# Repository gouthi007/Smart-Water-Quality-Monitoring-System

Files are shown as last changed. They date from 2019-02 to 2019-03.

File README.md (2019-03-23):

# Smart-Water-Quality-Monitoring-System

The aim of this project is to develop a Smart Water Quality Monitoring S System for testing the quality of water, using pH, temperature and u turbidity as the parameters, and User-Friendly Real-time Tracking Interface. The collective data is utilized to evaluate the quality of water, and to determine if the water quality is sufficient enough for domestic usage. The main goal is to develop a compact, cost-effective device to measure the appropriate parameters through the respective sensors, that uploads the compressed data to the cloud in a periodic basis, and to develop a Webpage that allows to monitor the quality levels on a real-time basis.

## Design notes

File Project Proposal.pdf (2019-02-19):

## EE701: Internet of Things: From Technology to Application

PROJECT PROPOSAL

Project Title | : Smart Water Quality Monitoring System
Team Members | : Hiren Aravind Murugudu Govindarajan
| Goutham Balasubramaniam
| Sai Ramya Gundala
| Zhe Li

Project Description : The aim of this project is to develop a Smart Water Quality Monitoring
S | System for testing the quality of water, using pH, temperature and
u | turbidity as the parameters, and a User-Friendly Real-time Tracking I
n | Interface. The collective data is utilized to evaluate the quality of water,
a | and to determine if the water quality is sufficient enough for domestic
s | usage. The main goal is to develop a compact, cost-effective, biosafe
e | device to measure the appropriate parameters through the respective
e | sensors, that uploads the compressed data to the cloud in a periodic b
a | basis, and to develop a Webpage that allows to monitor the quality-l e
v | levels on a real-time basis.

PROJECT OVERVIEW:

HARDWARE:

The following list of components will be used in the building of the monitoring device and is accompanied by the specifications and the cost for corresponding components. It is followed by links to the vendors for all the components.

Components | Model Number | Cost
Waterproof Temperature Sensor | DS18B20 | $10.99 (Set of 5)
Turbidity Sensor | SEN0189 | $19.69
pH Sensor | YY6237 | $33.59
Water Level Sensor | MC050-5 | $6.89 (Set of 5)
TI Board | CC2650 | Present with the team
SIGFOX Module | RC1692HP
Total | | $77.15

SENSORS’ DESCRIPTION:

1. Temperature Sensor: To measure the temperature of water (a requirement in cold places)
2. Turbidity Sensor: To indicate the level sediments/cloudiness by suspended particles in water. More turbidity can obstruct light to aquatic plants and also indicates the presence of high bacteria count.
3. pH Sensor: To indicate the presence of chemicals.
4. Water Level Sensor: To prevent the module from getting completely immersed by sending an alarm/notification.

SENSORS’ LINK:

### 1. Temperature Sensor-

https://www.amazon.com/HiLetgo-DS18B20-Temperature-Stainless-Waterproof/dp/B00M1PM55K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 (https://www.amazon.com/HiLetgo-DS18B20-Temperature-Stainless-Waterproof/dp/B00M1PM55K?hvadid=241906416474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)

### 2. Turbidity Sensor-

https://www.amazon.com/gp/product/B078JHBDJK/ref=ox_sc_act_title_2?smid=A2M99LKXDQEZXD&psc=1 (https://www.amazon.com/gp/product/B078JHBDJK/ref=ox_sc_act_title_2?smid=A2M99LKXDQEZXD&psc=1)

### 3. pH Sensor-

https://www.amazon.com/GAOHOU-PH0-14-Detect-Electrode-Arduino/dp/B0799BXMVJ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 (https://www.amazon.com/GAOHOU-PH0-14-Detect-Electrode-Arduino/dp/B0799BXMVJ?s=industrial)

### 4. Water Level Sensor-

https://www.amazon.com/gp/product/B01FDGU95Q/ref=ox_sc_act_title_3?smid=ADV3ON8ONZPPL&psc=1 (https://www.amazon.com/gp/product/B01FDGU95Q/ref=ox_sc_act_title_3?smid=ADV3ON8ONZPPL&psc=1)

SOFTWARE:

The project also involves developing a Static Webpage that provides a User-friendly Web-Interface(AWS Service) to allow real-time tracking of Water-Quality levels, which allows the user to see the latest data available or a time-series data for a particular location either by searching for that location or clicking on the corresponding location on the map. Once the hardware device is connected and sending data to the Sigfox Network, a native AWS IoT connector has to be configured to push the data to AWS cloud, which requires a CloudFormation script that will generate IAM roles and permissions. The data is stored in an Amazon DyanamoDB table by creating a manual rule. Also, Javascript and HTML is to be used to use the Google maps embed API interaction.

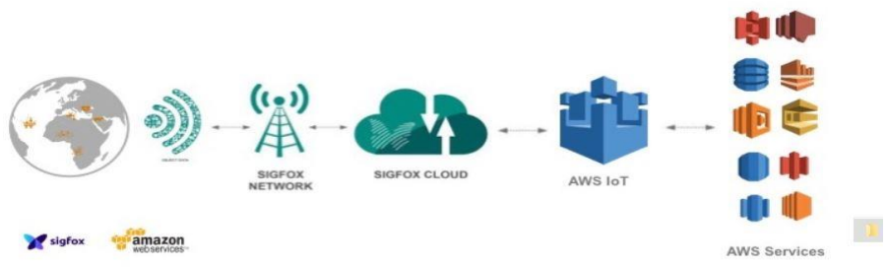
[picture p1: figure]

WORK PLAN/DIVISION of WORK:

Process Step | Resources Needed | Expected Effort | Due date
Hardware Requirements | Required: Hiren, Li Optional: Goutham, Ramya | 1-day of pre-work (3) 2-hour meetings | 11/11/2018
Hardware Development and Testing | Required: Hiren, Li, Goutham Optional: Ramya | 2-days of pre-work (8-10) 2-hour meetings | 11/18/2018
Hardware Enclosure Development | Required: Hiren, Li, Goutham Optional: Ramya | 1-day of pre-work (6-7) 2-hour meetings | 12/2/2018
Webpage Development | Required: Goutham, Ramya | (10) 2-hour meetings | 11/25/2018
System Integration and Testing | Required: Hiren, Goutham, Li, Ramya | (6) 2-hour meetings | 11/28/2018
Project Review And Remodeling | Required: Hiren, Goutham, Li, Ramya | (6) 2-hour meetings | 12/5/2018
Documentation/ Cost-Analysis | Required: Hiren, Goutham, Li, Ramya | (2) 2-hour meetings | 12/2/2018
Final Report | Required: Hiren,Goutham, Li, Ramya | (3) 2-hour meetings | 12/10/2018

Communication between the members of the team would be through Slack and weekly meetings would be conducted to update the weekly progress. The work progress would be tracked using Agile methodology and use Trello Board for managing the project.

TASKS:

The tasks have been divided into separate hardware and software categories along with the integration in the later part after individual tasks have been completed.

Software

- Code development for the data to be collected by the sensors and transferred from the microcontroller to the Cloud(AWS).
- Code development for the analysis of data which has been transferred to the Cloud.
- Webpage development using JavaScript, HTML and XML with Google Map API interaction.

Hardware

- Sensor interfacing with the microcontroller.
- Building the prototype for the physical container which holds the whole circuit using CAD.
- Building the container based on the model.

Others

- Integrating the hardware and software developments.
- Generate a technical report and a user manual.

DIVISION OF WORK:

The team is divided into two sub-teams; Hardware and Software team with each team consisting of two members each. The hardware team will concentrate on the device development including the assembly of sensors in a physical container. The software team will be working on software development involving coding and web development. After the sub-team specific tasks are completed, the teams will work together to integrate the different components and initial testing, and redesigning (if necessary) based on the feedback.

Hardware: Hiren Aravind Murugudu Govindarajan, Zhe Li

Software: Goutham Balasubramaniam, Sai Ramya Gundala

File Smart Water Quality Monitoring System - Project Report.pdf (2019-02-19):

# SMART WATER-QUALITY MONITORING SYSTEM

PROJECT OBJECTIVE:

The goal of this project is to formulate a simpler solution for one of the most complex problems that is developing in the present. The main objective is to develop an inexpensive, scalable solution that allows remote monitoring and tracking of Water-Quality of large Water bodies. Even though there are many devices that are available in the market to measure specific water parameters like pH, temperature, etc. there is no commercially feasible product that gives a comprehensive quality measurement that allows for remote monitoring.

PROJECT DESCRIPTION:

The aim of this project is to develop a Smart Water Quality Monitoring System for testing the quality of water, using pH and turbidity as the parameters, and a User-Friendly Real-time Tracking Interface. The collective data is utilized to evaluate the quality of water, and to determine if the water quality is sufficient enough for domestic usage. The main goal is to develop a compact, cost-effective, bio-safe device to measure the appropriate parameters through the respective sensors, that uploads the compressed data to the cloud in a periodic basis, and to develop a Webpage that allows to monitor the quality levels on a real-time basis.

DESIGN OVERVIEW:

A combination of pH, turbidity sensors, and an algorithm is implemented that evaluates the quality of the water and a water level sensor is used to protect the device. Once, it’s evaluated, a packet is created with these data concatenated into a single data frame and transmitted via Sigfox module to the Sigfox cloud. Here, a number of callback functions are implemented to trigger a set of AWS IoT Rules, that perform a variety of actions including pushing data to the database, sending Email and SMS notifications to the Administrators and Subscribed users.

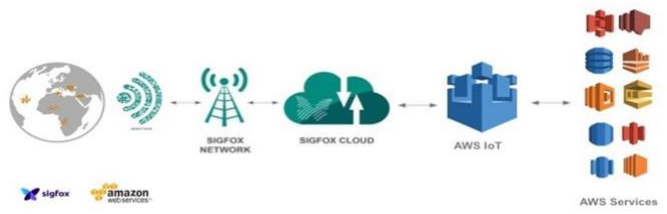
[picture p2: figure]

SYSTEM IMPLEMENTATION:

HARDWARE:

The hardware end of the project is implemented with 3 sensors, namely pH, turbidity and water-level indicator. The brain of the project is the CC2650 Launchpad, which integrates the data acquired by the sensors and feeds into the Sigfox network using Sigfox module.

The following is a list of above-mentioned components that are used in the building of the monitoring device and is accompanied with the specifications and the cost for corresponding components. It is followed by links to the vendors for all the components.

COMPONENTS | MODEL NUMBER | COST
Turbidity Sensor | SEN0189 | $19.69
pH Sensor | YY6237 | $33.59
Water-Level Indicator | MC050-5 | $3.5
TI Launchpad | CC2650 | $30
Sigfox Module | RC1692HP | $25
TOTAL | | $111.78

Table 1

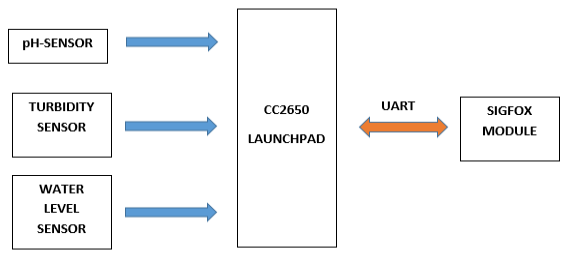
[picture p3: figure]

TURBIDITY SENSOR:

The turbidity sensor measures the quality of water by measuring its turbidity. The principle is that light is transmitted to detect particles that are suspended in water by measuring the scattering rate. This scattering rate changes with amount of Total Suspended Solids (TSS). Scattering rate is more when TSS is more, which in turn returns high voltage. If the liquid is clear, then there is no scattering and thus, low voltage is observed. Figure 1 shows the SEN0189 Turbidity sensor that has been integrated in the module.

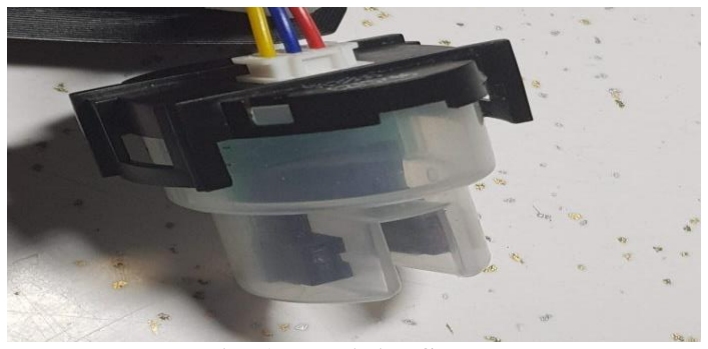
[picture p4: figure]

Fig. 1 Turbidity Sensor

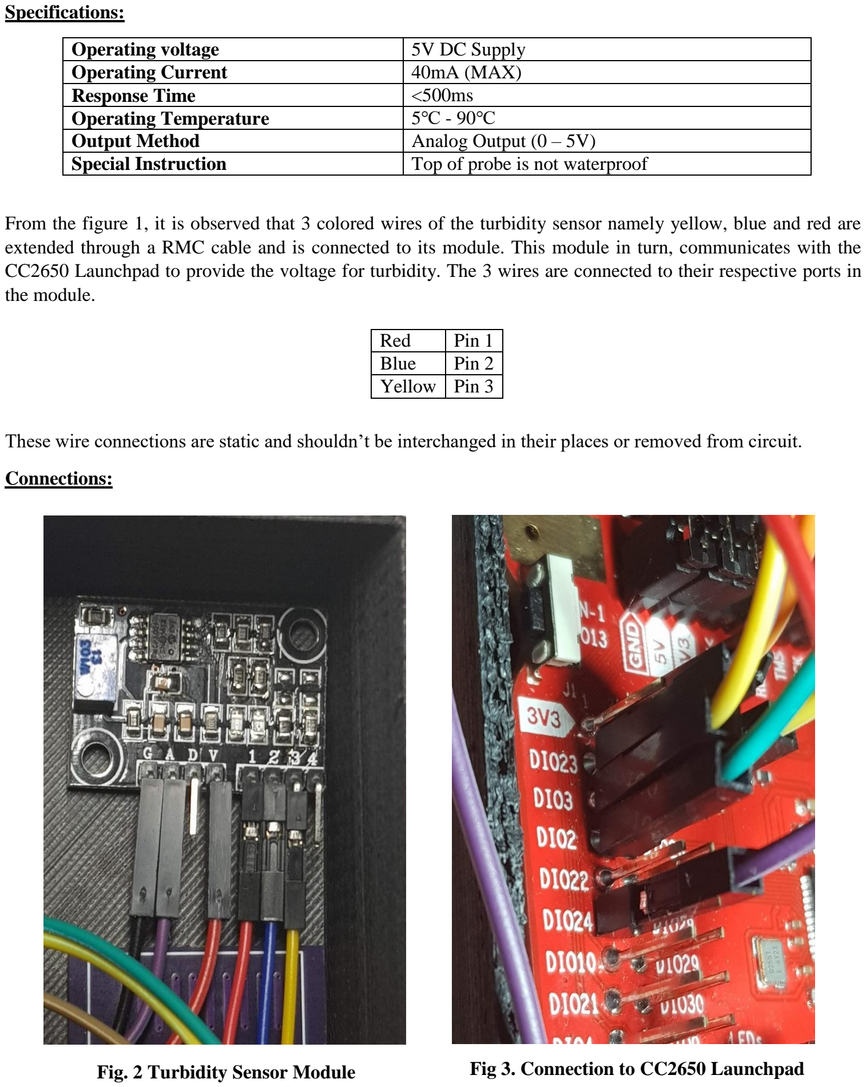
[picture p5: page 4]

Specifications:

Operating voltage | 5V DC Supply
Operating Current | 40mA (MAX)
Response Time | <500ms
Operating Temperature | 5℃ - 90℃
Output Method | Analog Output (0 – 5V)
Special Instruction | Top of probe is not waterproof

From the figure 1, it is observed that 3 colored wires of the turbidity sensor namely yellow, blue and red are extended through a RMC cable and is connected to its module. This module in turn, communicates with the CC2650 Launchpad to provide the voltage for turbidity. The 3 wires are connected to their respective ports in the module.

These wire connections are static and shouldn’t be interchanged in their places or removed from circuit.

Connections:

Red | Pin 1
Blue | Pin 2
Yellow | Pin 3
Fig. 2 Turbidity Sensor Module | Fig 3. Connection to CC2650 Launchpad

Module | CC2650 Launchpad
G → Ground | GND
A → Analog o/p | DIO24
V → Voltage | 5V

pH SENSOR:

pH is an indication of the concentration of Hydrogen ions present in a given solution. This can be quantified by using a pH sensor, which has 2 electrodes already embedded in it. The first one is a reference electrode (typically Ag/AgCl) and the other electrode is sensitive to the hydrogen ions. The potential difference created by these electrodes in the given solution is used to estimate the pH of that solution. This is the working principle of the pH sensor. pH scale ranges from 0 – 14 to estimate the acidity or alkalinity, where 0~7 denotes acidic solutions and 7~14 denotes basic solutions. pH value of 7 is considered to be neutral.

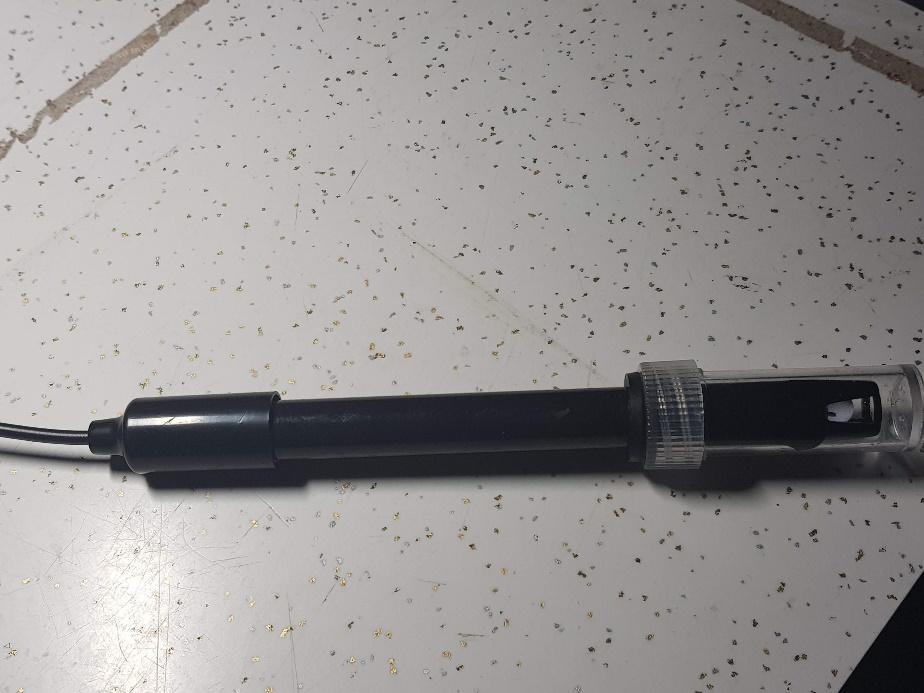
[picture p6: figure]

Fig. 4 pH sensor

Probe Specifications:

Electrode Type | pH Range | Temp | Zero Point | Response Time
65-1 | 0-14 | 0-80℃ | 7 ± 1 | < 2 minutes

Circuit Specifications:

Supply Voltage | 5V
Current | 5 – 10mA
Consumption | ≤ 0.5W
Working Temperature | 10-50℃
Green LED | Indication for Power

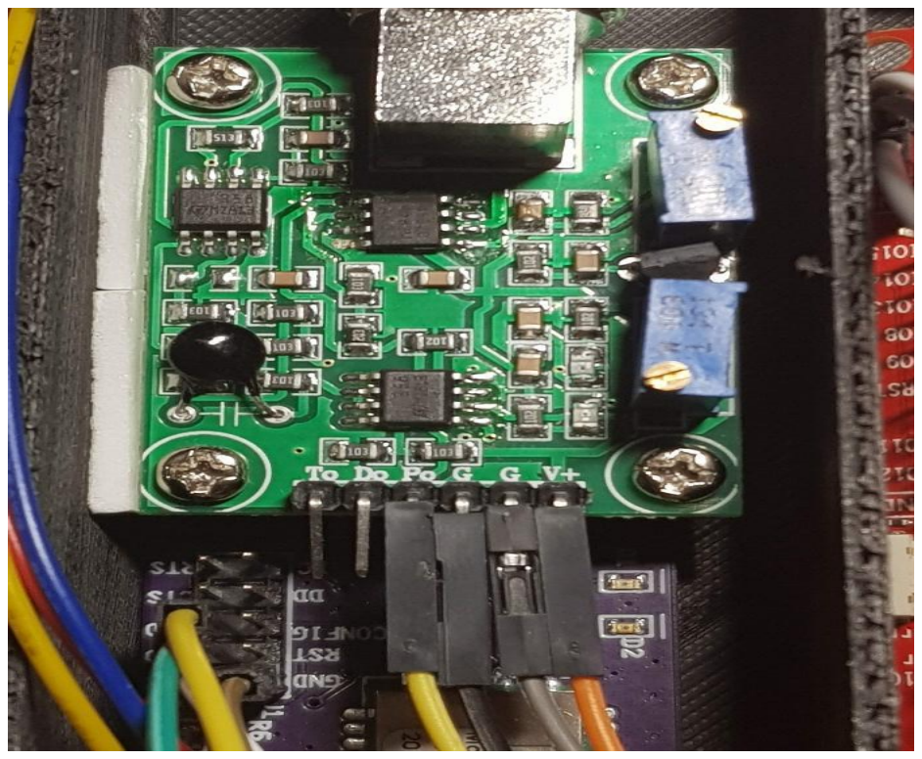
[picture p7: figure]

Fig. 5 pH Sensor Module

Sensor Calibration:

The pH sensor has to be handled carefully while immersing in solutions. The sensor takes a min or two to accurately display the voltage. In order to check or calibrate the sensor to a known solution of certain concentration, buffer powders can be used which are commercially available in the market in the pH values of 4.00 and 6.86. They have to be mixed with distilled water before the probe is inserted into the solution.

Since the probe returns only voltages on the console, it is necessary to take two readings of the voltage during calibration: one voltage using pH 4.0 solution and second voltage using 6.86 pH solution. The voltages are fed to the 2-point form,

y = mx + b

in order to deduce the equation for converting the measured voltage to pH. Here, y is the pH value and x is the voltage.

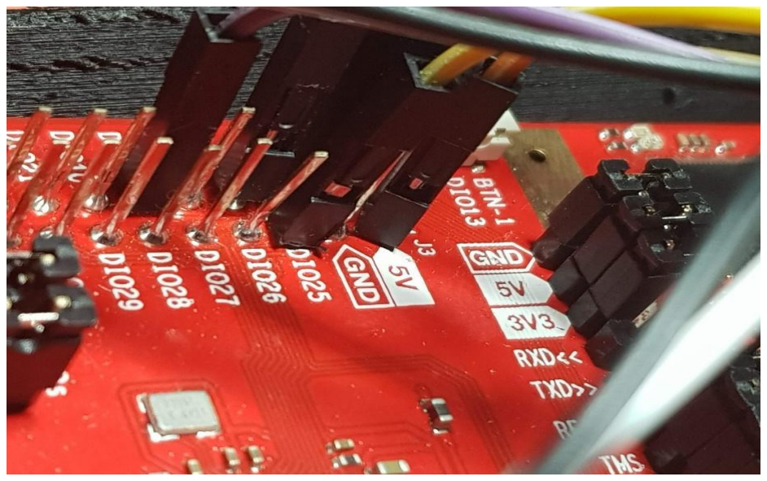
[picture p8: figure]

Fig. 6 Connection to CC2650 Launchpad

Connections:

Module | CC2650 Launchpad
V+ → Supply voltage | 5V
G → Ground | GND
G → Ground | GND
Po → Analog o/p | DIO25

WATER LEVEL SENSOR:

The water level sensor is used in the project in order to make sure the test water doesn’t cross the critical limit, because beyond this point the circuitry is not water compatible. Filaments in parallel are exposed on the body of the sensor, which sense the level of water when dipped into it. Based on the height of water, a parameter is sent through the ‘S’ pin of the water level sensor to the analog DIO23 pin of the Launchpad. It is then converted into equivalent voltage, which can be coded in a way suitable for the 3D printed design. Figure 7 shows the MC050-5 water level sensor.

Specifications:

As shown in Figure 3, the output of the water level sensor is connected to the DIO23 pin of CC2650 Launchpad, while the ‘+’ and ‘-‘ pins of the sensor indicate voltage and ground respectively.

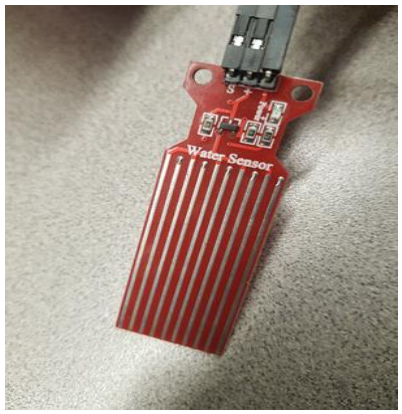
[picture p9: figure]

Fig. 7 Water-Level Indicator Sensor

Connections:

TEXAS INSTRUMENTS CC2650 LAUNCHPAD:

CC2650 Launchpad is ideal for the project as it aims at Low Power Wide Area Networks (LPWAN). It has a built-in 32-bit ARM processor and runs at the frequency of 48MHz. A sensor controller is embedded in the device which is an ultra-low power sensor and is best suitable for interfacing physical sensors to collect both analog and digital values and puts the rest of the system in sleep mode. Also, this device supports a variety of protocols such as SPI, I2C to name a few.

Specifications:

The pH, turbidity and the water-level sensors are interfaced to the CC2650 Launchpad in their corresponding pin positions. ADC conversion is used to convert the raw values read out by these water-environment sensors and are meant to present in a readable and perceptible manner for understanding. The CC2650 Launchpad has pins projected on top and bottom parts of the board for convenient interface. This feature is helpful in the project as all the 3 sensors use 5V supply while one side of the board (top or bottom) has only 2 pins for 5V supply.

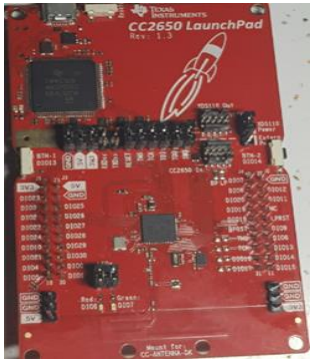
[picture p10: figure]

Fig 8. CC2650 Launchpad

SIGFOX:

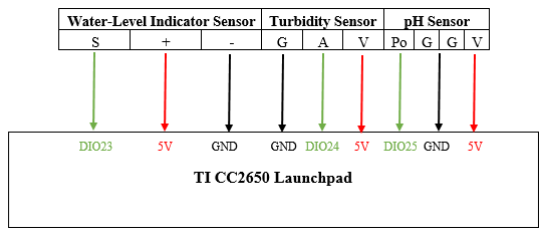
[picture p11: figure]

Sigfox is a Low Powered Wide Area Network (LPWAN) which acts as a provider for Internet of Things (IoT) applications. Key aspects of Sigfox are:

- Low power - Power consumption is minimal as most of the assets are unpowered.
- Long range - The coverage with one station ranges up to 10 miles.
- Ease of use - Integration of assets and backend.
- Interference - Highly resistant

It uses Ultra Narrow Band BPSK (Binary Phase Shift Keying) modulation. Each Sigfox device also has its own ID which is unique from all other Sigfox devices. Synchronization is not required in a Sigfox network, thus jamming the receiver has no effect practically.

In our project, the sensors collect all the data which is integrated in the Launchpad. Then, a connection is established with the Sigfox network with various commands, including the device ID for authentication. When the connection is successfully established, the data is pushed to the Sigfox base station, which in turn delivers the data to the Sigfox cloud. The data can be viewed in the backend.

Figure 10 shows the Sigfox Module that was used in our project. Since it was designed by the EE Department of UB itself, the cost is comparatively inexpensive than the original Sigfox device.

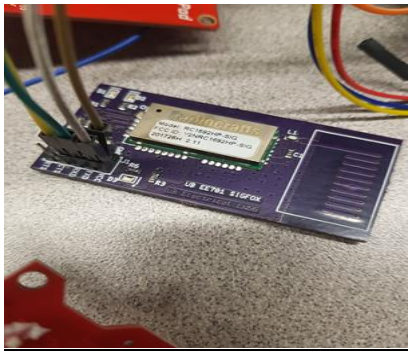
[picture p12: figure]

Fig. 10 Sigfox Module

SOFTWARE:

Firmware for Hardware:

In the main function, there is only one task for sigfox.

In the sigfox task, the first step is the configuration of sigfox.

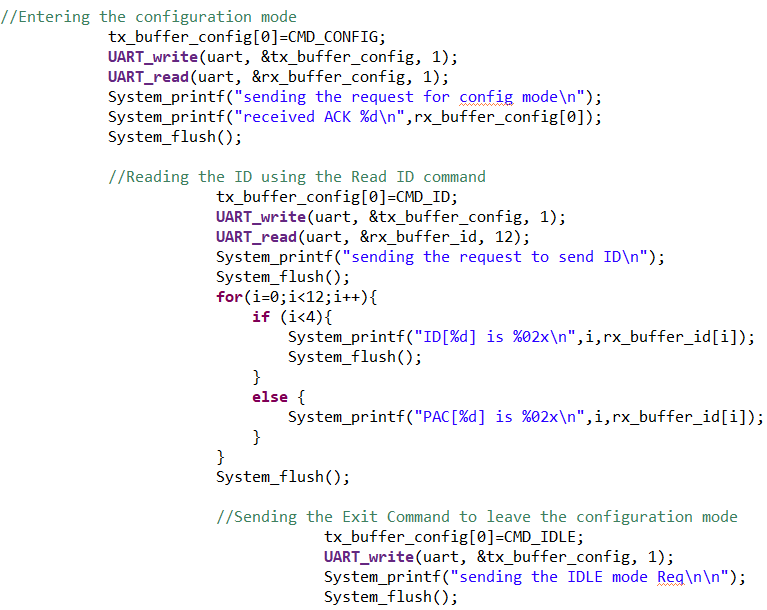
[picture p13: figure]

then “while(1)” loop is used. In this loop, a water_level function, a turbidity function and a ph function are called. According to the information collected from the turbidity function and the ph function, “0x01” meaning “water is safe” or “0x02” meaning “water is unsafe” is given to tx_buffer_data[1]. By using “UART_write”, all the data is transmitted. At the end of the loop, “task_sleep” can control the interval of every two transmissions.

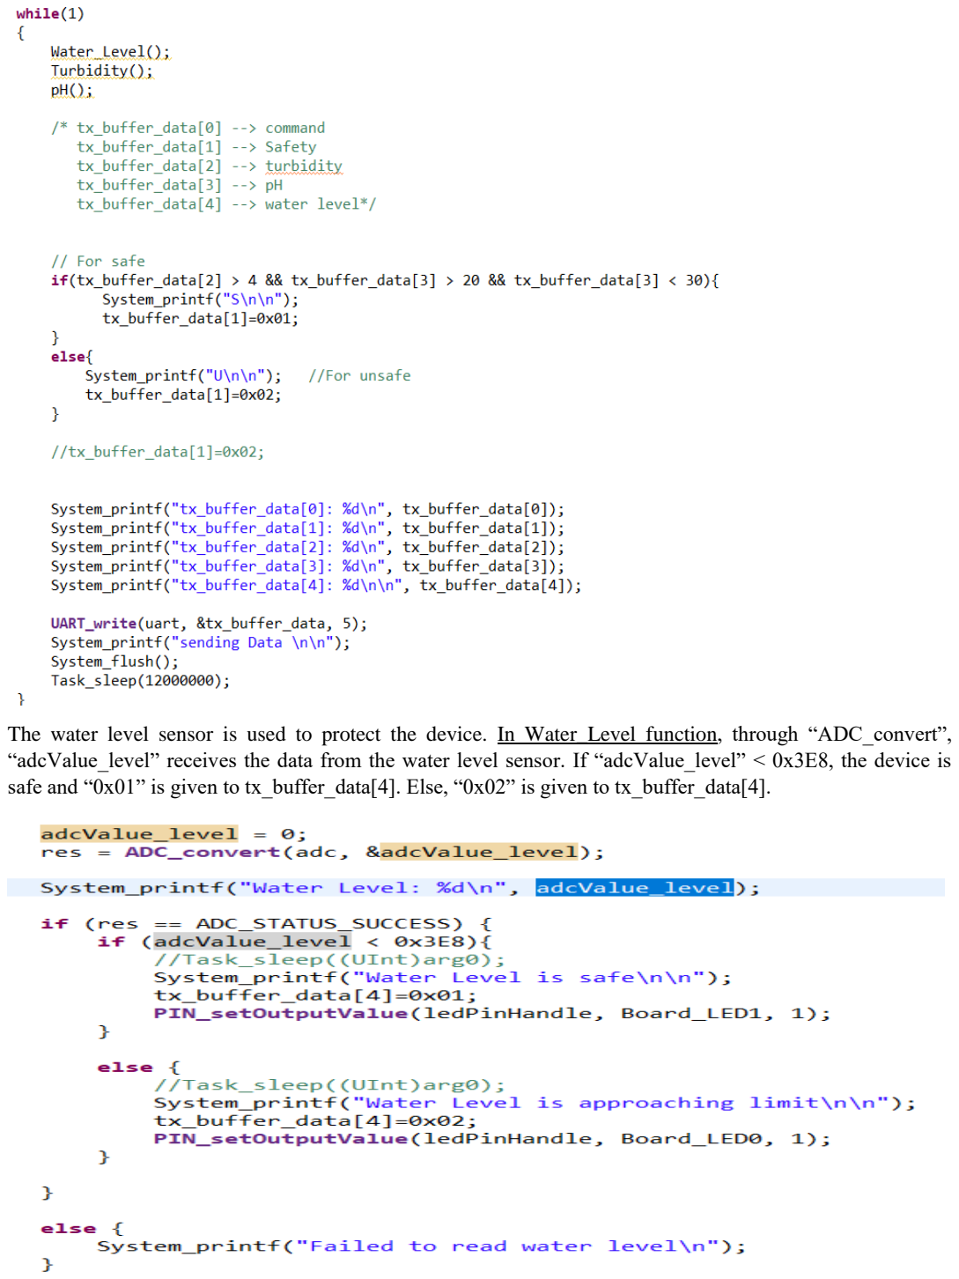
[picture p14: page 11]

The water level sensor is used to protect the device. In Water_Level function, through “ADC_convert”, “adcValue_level” receives the data from the water level sensor. If “adcValue_level” < 0x3E8, the device is safe and “0x01” is given to tx_buffer_data[4]. Else, “0x02” is given to tx_buffer_data[4].

In Turbidity function, “adcValue_turbidity” stores the data converted by “ADC_convert”. Then send the data to tx_buffer_data[2].

In pH function, “adcValue_pH” stores the data converted by “ADC_convert”. Then send the data to tx_buffer_data[3].

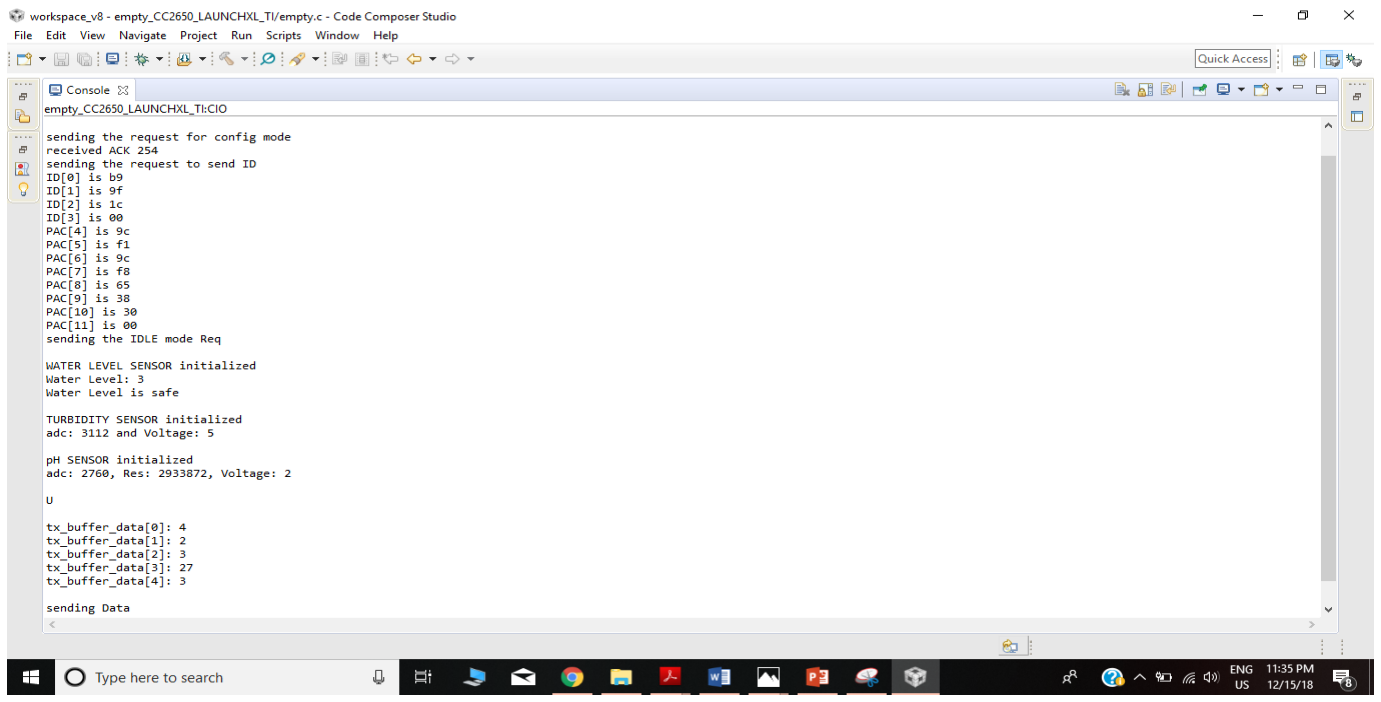
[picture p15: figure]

The first part shows the sigfox module configuration is successful.

In the water level sensor part, if the value from the sensor is lower than a threshold (0x3E8), the device is considered safe. Because the device is not waterproof.

In the turbidity sensor part, according to the drinking water standard, if “adc” > 4000, which means the turbidity is lower than 1 NTU, the water quality is safe. If not, the water quality is unsafe.

In the ph sensor part, according to the drinking water standard, if 2000 <= “adc” <= 3000, which means the ph is from 4 to 10, the water quality is considered safe. If not, the water quality is unsafe.

According to the “adc” of turbidity and the “adc” of ph, “U” is printed as unsafe, “S” is printed as safe.

The next part is the sigfox packet structure.

“tx_buffer_data[0] = 4” means the data length is 4 bytes.

“tx_buffer_data[1] ” stores the water quality information. “1” represents “safe” and “2” represents “unsafe”.

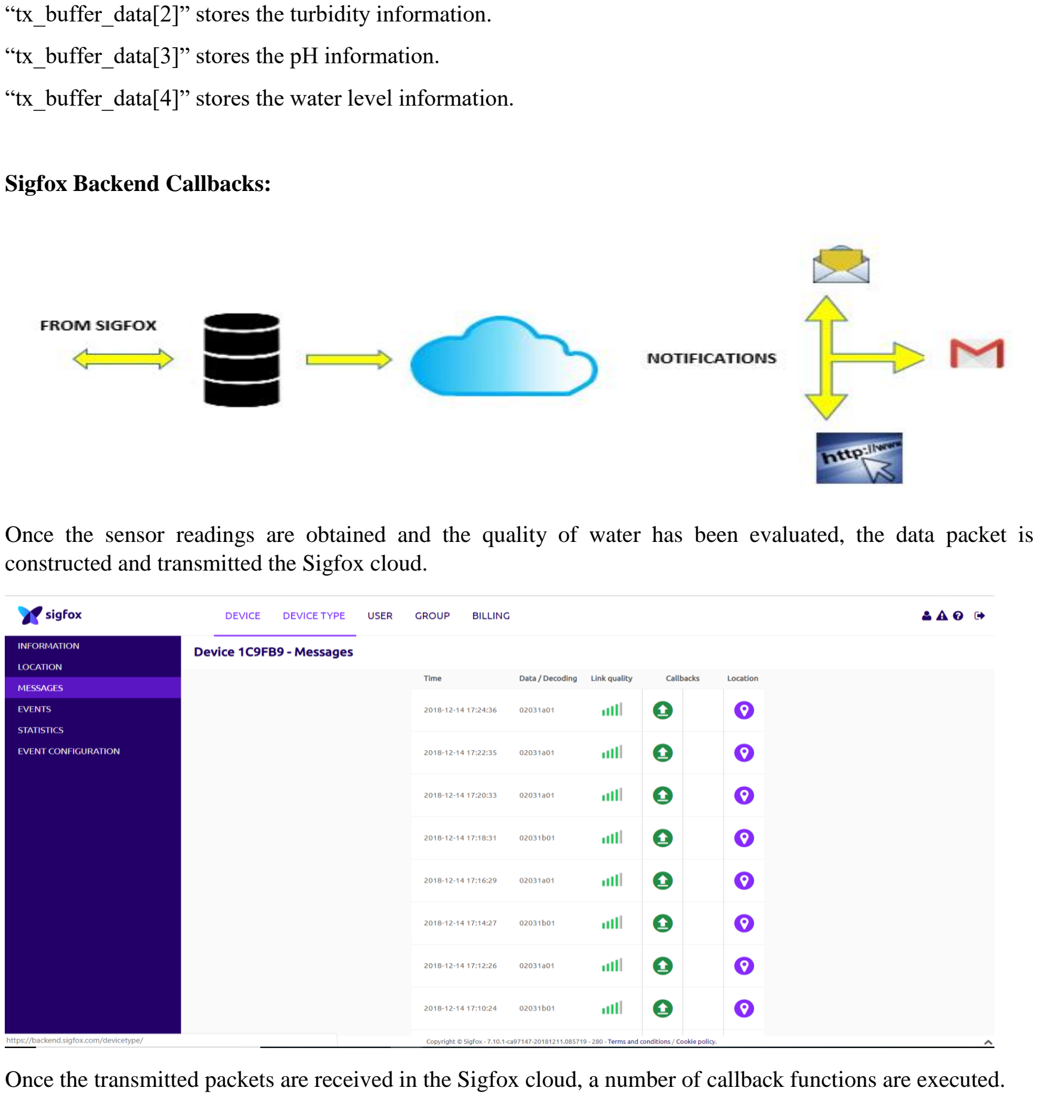
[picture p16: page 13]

“tx_buffer_data[2]” stores the turbidity information.

“tx_buffer_data[3]” stores the pH information.

“tx_buffer_data[4]” stores the water level information.

Sigfox Backend Callbacks:

Once the sensor readings are obtained and the quality of water has been evaluated, the data packet is constructed and transmitted the Sigfox cloud.

Once the transmitted packets are received in the Sigfox cloud, a number of callback functions are executed.

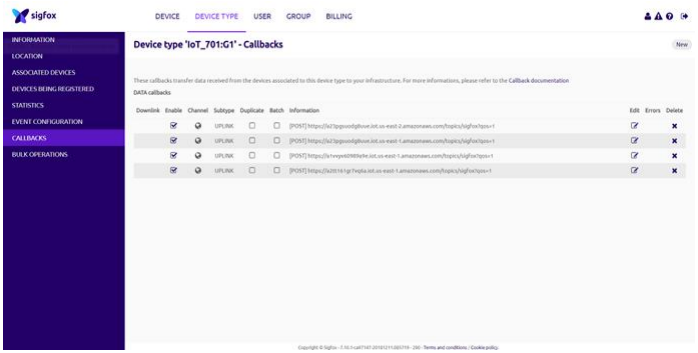
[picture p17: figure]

These callback functions are linked to different AWS Services which will be triggered based on the payload, by AWS IoT Rules defined in the AWS IoT Core.

Rule Definitions:

Sigfox:

This rule is used to check for all incoming data from sigfox backend and pushes all the data with the entire specifications to two different DynamoDB tables using the ‘deviceid’ as ‘Partition Key’ and the ‘timestamp’ as the ‘Sort key’. This is done to account for the extremely rare case that data fails to be pushed to one of the tables so that another table can be utilized as a fail-safe mechanism.

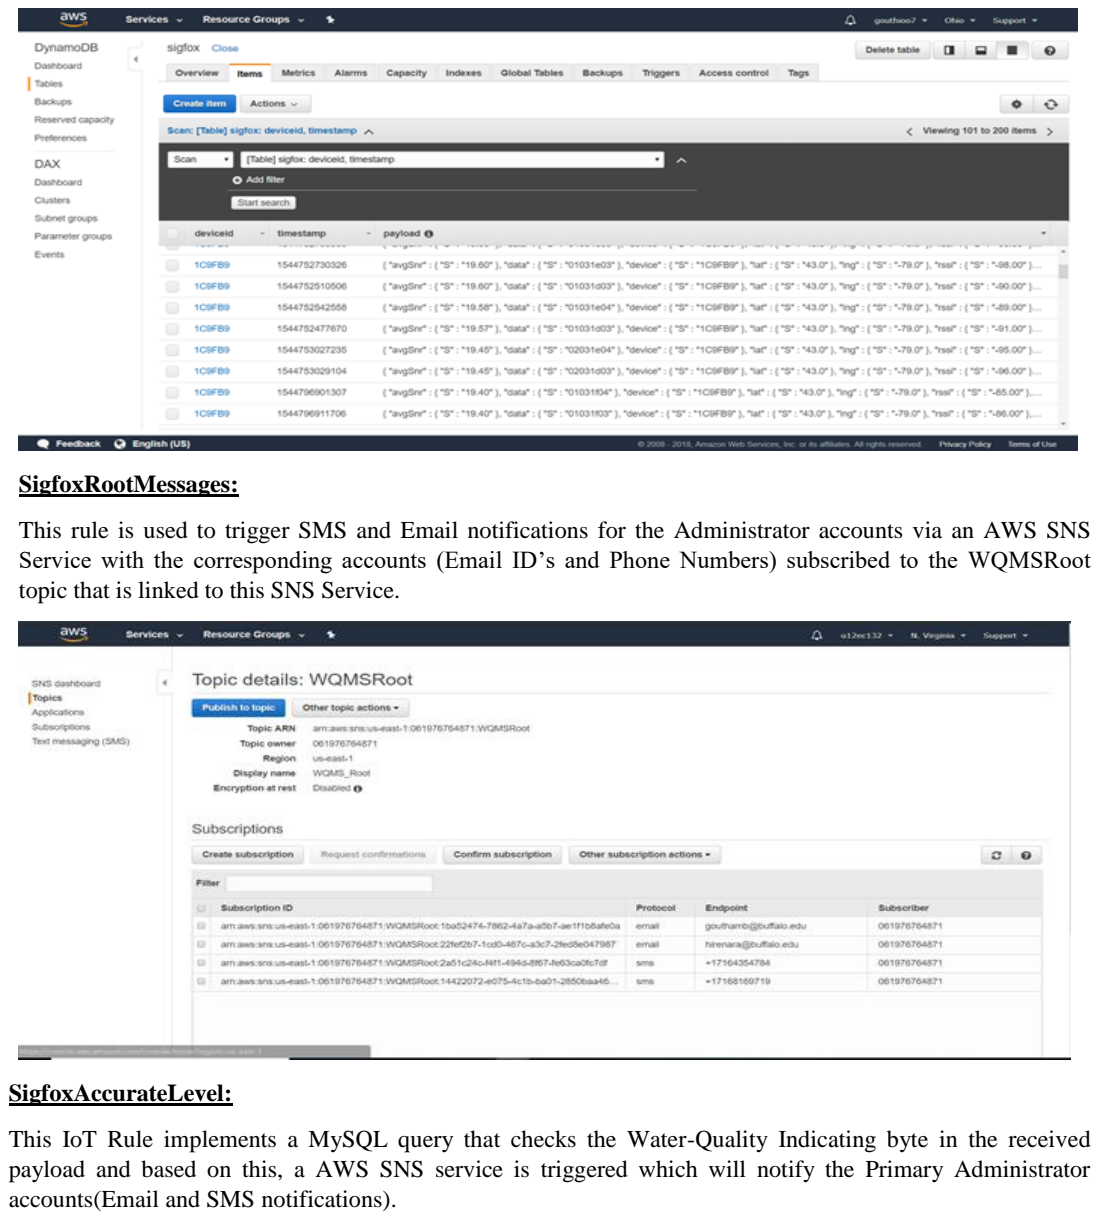
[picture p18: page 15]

SigfoxRootMessages:

This rule is used to trigger SMS and Email notifications for the Administrator accounts via an AWS SNS Service with the corresponding accounts (Email ID’s and Phone Numbers) subscribed to the WQMSRoot topic that is linked to this SNS Service.

SigfoxAccurateLevel:

This IoT Rule implements a MySQL query that checks the Water-Quality Indicating byte in the received payload and based on this, a AWS SNS service is triggered which will notify the Primary Administrator accounts(Email and SMS notifications).

SigfoxWaterQualityLevel:

This rule also checks the Water-Quality Indicating byte in the received payload and if the quality is determined to be unsafe, an AWS SNS Service is triggered which sends SMS and Email notifications to everyone subscribed for the service as well as administrators so necessary actions can be taken as early as possible.

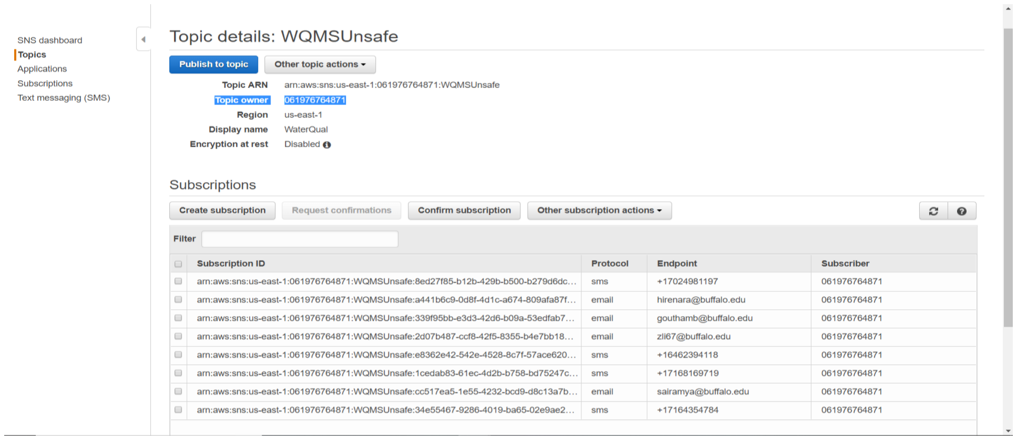
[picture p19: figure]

User-Interface:

As mentioned above, there are three User-Interfaces available, two of which are Internet Network connection based and one is Cellular Network connection based, to ensure that in the cases of failure of either of the systems, there is a backup mechanism that is implemented to deliver the notifications.

The following images are the notifications that are received by the Administrator Account via Email and SMS. The entire payload is displayed and also the Warning message indicating the data of the sensors is also sent, as two separate notifications, through Email and SMS.

The following images represent the notifications received by accounts that are subscribed for the service.

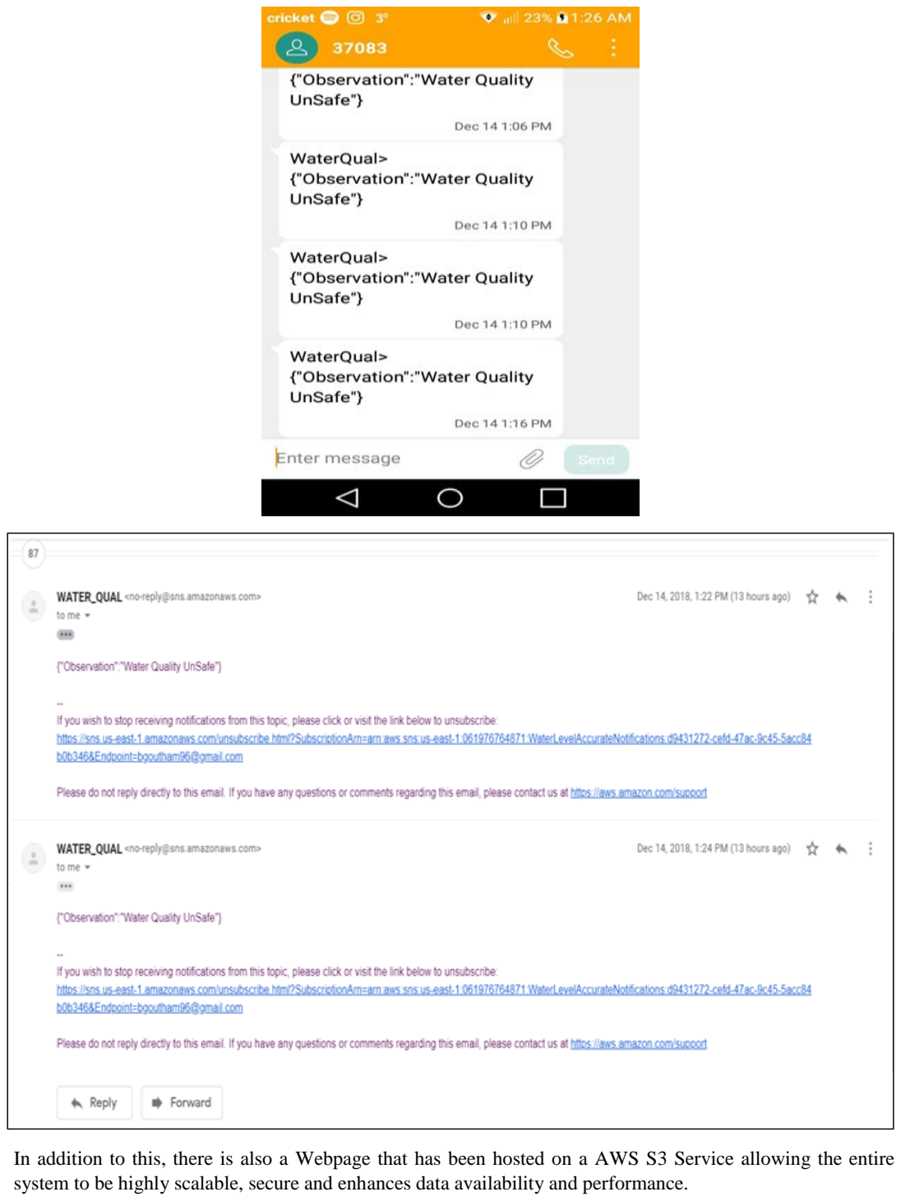
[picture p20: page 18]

In addition to this, there is also a Webpage that has been hosted on a AWS S3 Service allowing the entire system to be highly scalable, secure and enhances data availability and performance.

FRONTEND (CLIENT-SIDE):

The frontend is designed to access details about the condition of water from multiple locations which has deployed this system from the client side. This has been designed using HTML, CSS and Javascript. The code is used to access data from Amazon DynamoDB and present it in the form of an interactive webpage. The webpage is hosted on Amazon S3.

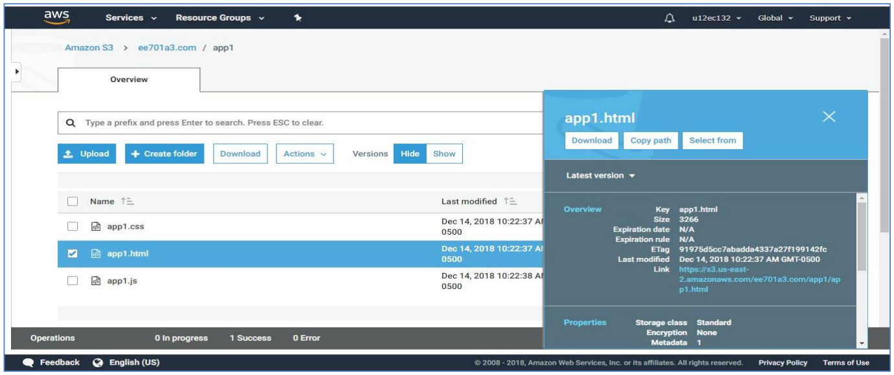
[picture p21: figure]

Amazon S3(Simple Storage Service) is storage for the Internet. It is designed to make web-scale computing easier for developers. Amazon S3 has a simple web services interface that can be used to store and retrieve any amount of data, at any time, from anywhere on the web.

First a bucket on S3 called ee701a3.com (https://s3.console.aws.amazon.com/s3/) was created in which the three files of HTML, CSS and JavaScript have been added. A bucket is a container for objects stored in Amazon S3. Every object is contained in a bucket. Through the link associated with the HTML file, the webpage can be accessed.

From the client side, when this page is opened, there is an integrated map, which shows the locations where the module has been deployed in the form of markers. Clicking on the marker or selecting the waterbody from the list gives the details of the waterbody in terms of whether it is safe or not, it's turbidity, pH and water level measurements.

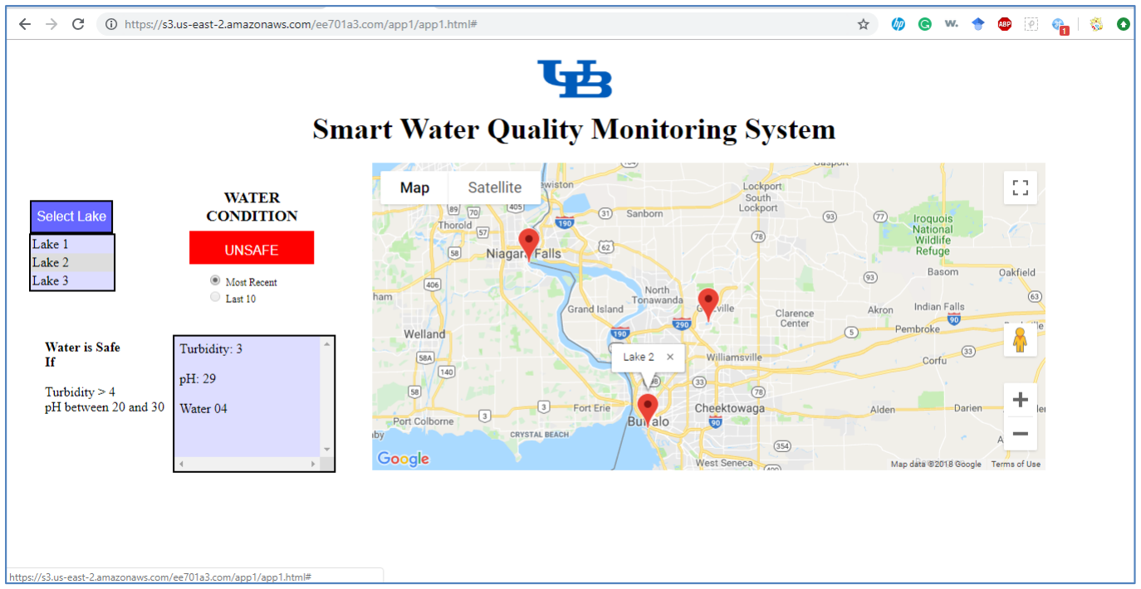
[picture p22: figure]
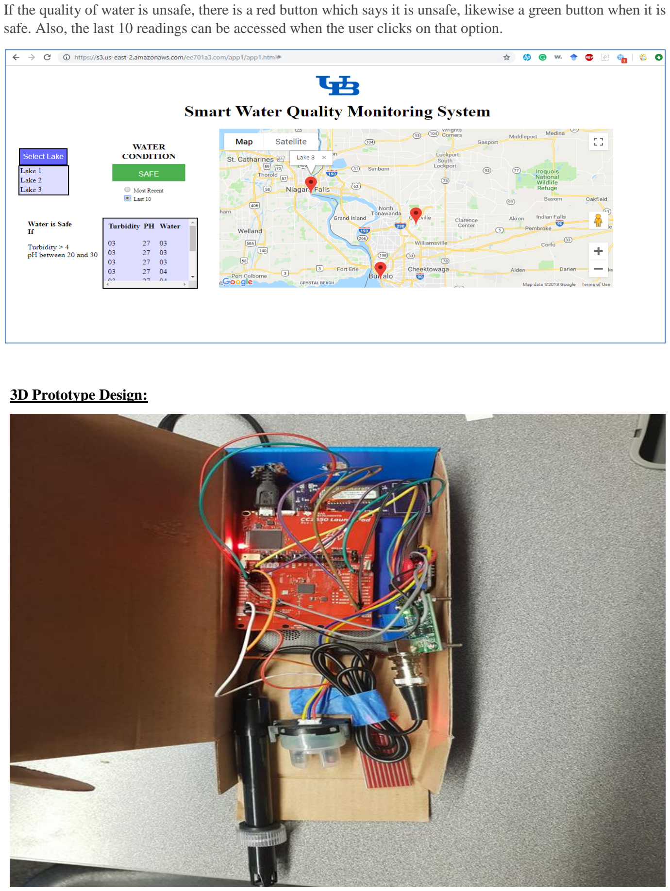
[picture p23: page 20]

If the quality of water is unsafe, there is a red button which says it is unsafe, likewise a green button when it is safe. Also, the last 10 readings can be accessed when the user clicks on that option.

3D Prototype Design:

The preliminary prototype was designed using a cardboard box as the design base inside which all the sensors, modules and the LaunchPad were arranged. The appropriate connections along with a power source (Power Bank) were given and all the components were attached firmly to the base and the experiment was run to ensure the proper functioning of the device as a whole as well as the individual components.

Once the preliminary prototype was tested, the actual prototype was designed by accounting for each component and their place in the prototype. Necessary compartments were designed to isolate the power-source and the LaunchPad from rest of the components to provide additional protection from water. Additionally, separate compartment was designed to place the sigfox modules and the other interfacing modules for the sensors.

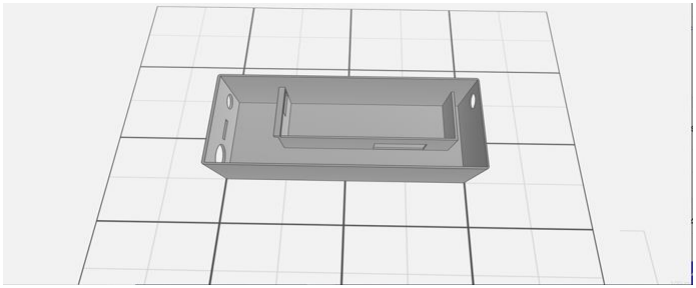
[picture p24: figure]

In addition to this, a cover resembling two rectangular prisms mounted on each other with different dimensions was also designed to provide an air-tight seal to the entire device once the components are fixed to the base with corresponding connections and interfaces.


CONCLUSION AND FUTURE WORK:

We have successfully designed and implemented an economical, scalable and efficient Internet of Things solution to track the water quality of large water bodies which can enable users to access the water quality information from multiple locations in real-time at the convenience of their mobile phone.

The future scope of this project includes:

- Developing specific algorithms to define the safety in terms of various defined activities. (e.g. Cattle Consumption, Human Consumption, Watersports, etc.) and integrating different types of sensors to characterize water-quality.
- Generating a compact PCB design for fabrication which will reduce the production cost of each device by up to 50%
- Increasing the number of devices to compare the variation of water quality from environmental perspective across different regions.

INSTRUCTION GUIDE FOR DEMONSTRATION:

1) If the module is intact with all the sensors connected, connect the power supply to the device. This can be done by a power bank or plugging it to the laptop using micro-USB cable.
2) The model has to be immersed in the test water carefully, making sure that water does not enter near the circuit and only the sensors are present in the water.
3) Leave it in this position for a minimum of 2-3 minutes for the sensor readings to be accurate.
4) The pH sensor has to be recalibrated every time there is significant change in the pH value to be measured.
5) The webpage for the demo can be accessed

https://s3.us-east-2.amazonaws.com/ee701a3.com/app1/app1.html

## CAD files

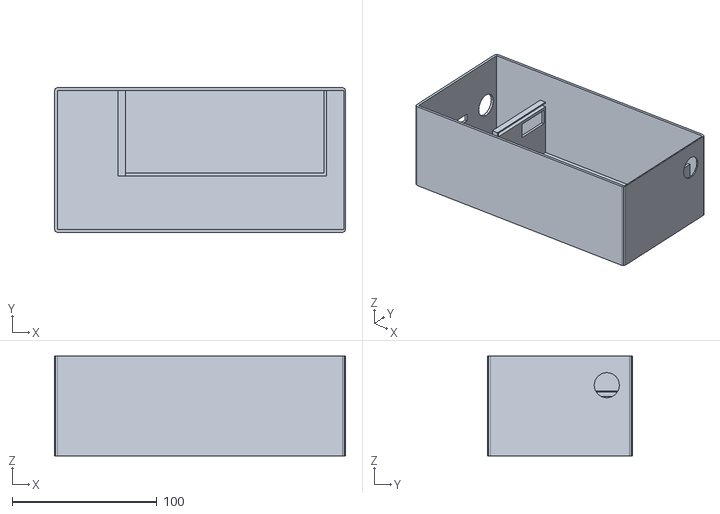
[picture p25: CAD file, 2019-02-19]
Water_Quality_Monitoring_System.stl
201.0 x 100.0 x 69.0

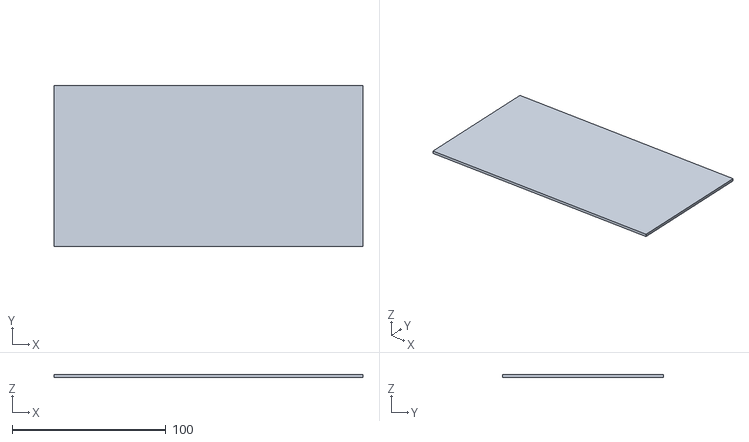
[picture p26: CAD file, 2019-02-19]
Water_Quality_Monitoring_System_top.stl
201.0 x 105.0 x 2.00

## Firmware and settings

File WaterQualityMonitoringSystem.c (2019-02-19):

/*
 * Copyright (c) 2015-2016, Texas Instruments Incorporated
 * All rights reserved.
 *
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
 * *  Redistributions of source code must retain the above copyright
 *    notice, this list of conditions and the following disclaimer.
 *
 * *  Redistributions in binary form must reproduce the above copyright
 *    notice, this list of conditions and the following disclaimer in the
 *    documentation and/or other materials provided with the distribution.
 *
 * *  Neither the name of Texas Instruments Incorporated nor the names of
 *    its contributors may be used to endorse or promote products derived
 *    from this software without specific prior written permission.
 *
 * THIS SOFTWARE IS PROVIDED BY THE COPYRIGHT HOLDERS AND CONTRIBUTORS "AS IS"
 * AND ANY EXPRESS OR IMPLIED WARRANTIES, INCLUDING, BUT NOT LIMITED TO,
 * THE IMPLIED WARRANTIES OF MERCHANTABILITY AND FITNESS FOR A PARTICULAR
 * PURPOSE ARE DISCLAIMED. IN NO EVENT SHALL THE COPYRIGHT OWNER OR
 * CONTRIBUTORS BE LIABLE FOR ANY DIRECT, INDIRECT, INCIDENTAL, SPECIAL,
 * EXEMPLARY, OR CONSEQUENTIAL DAMAGES (INCLUDING, BUT NOT LIMITED TO,
 * PROCUREMENT OF SUBSTITUTE GOODS OR SERVICES; LOSS OF USE, DATA, OR PROFITS;
 * OR BUSINESS INTERRUPTION) HOWEVER CAUSED AND ON ANY THEORY OF LIABILITY,
 * WHETHER IN CONTRACT, STRICT LIABILITY, OR TORT (INCLUDING NEGLIGENCE OR
 * OTHERWISE) ARISING IN ANY WAY OUT OF THE USE OF THIS SOFTWARE,
 * EVEN IF ADVISED OF THE POSSIBILITY OF SUCH DAMAGE.
 */

/*
 *  ======== empty.c ========
 */
/* XDCtools Header files */
#include <xdc/std.h>
#include <xdc/runtime/System.h>
#include <ti/sysbios/knl/Swi.h>

/* BIOS Header files */
#include <ti/sysbios/BIOS.h>
#include <ti/sysbios/knl/Clock.h>
#include <ti/sysbios/knl/Task.h>

/* TI-RTOS Header files */
// #include <ti/drivers/I2C.h>
#include <ti/drivers/PIN.h>
// #include <ti/drivers/SPI.h>
#include <ti/drivers/UART.h>
// #include <ti/drivers/Watchdog.h>

/* Driver Header files */
#include <ti/drivers/ADC.h>
#if defined(CC2650DK_7ID) || defined(CC1310DK_7XD)
#endif

#include <ti/drivers/ADCBuf.h>
/* Board Header files */
#include "Board.h"
#define TASKSTACKSIZE_sigfox   1024

/* ADC sample count */
#define ADC_SAMPLE_COUNT  (10)

#define TASKSTACKSIZE   768

Task_Struct task0Struct;
Task_Struct task1Struct;
Task_Struct task2Struct;
Task_Struct task3Struct;

Char task0Stack[TASKSTACKSIZE];
Char task1Stack[TASKSTACKSIZE];
Char task2Stack[TASKSTACKSIZE];
Char task3Stack[TASKSTACKSIZE_sigfox];

/* ADC conversion result variables */
uint16_t adcValue_level;
uint16_t adcValue_turbidity;
uint16_t adcValue_pH;

/* Pin driver handle */
static PIN_Handle ledPinHandle;
static PIN_State ledPinState;

#define CMD_CONFIG 0x00
#define CMD_ID 0x39
#define CMD_IDLE 0x58

extern Swi_Handle SWI0;

UART_Handle uart;
UART_Params uartParams;
uint8_t tx_buffer_config[1];
uint8_t rx_buffer_config[1];
uint8_t tx_buffer_data[5];
uint8_t rx_buffer_id[13];

//some variable
int i=0;

/*
 * Application LED pin configuration table:
 *   - All LEDs board LEDs are off.
 */
PIN_Config ledPinTable[] = {
    Board_LED0 | PIN_GPIO_OUTPUT_EN | PIN_GPIO_LOW | PIN_PUSHPULL | PIN_DRVSTR_MAX,
    Board_LED1 | PIN_GPIO_OUTPUT_EN | PIN_GPIO_LOW | PIN_PUSHPULL | PIN_DRVSTR_MAX,
    PIN_TERMINATE
};

Void taskFxn_sigfox(UArg arg0, UArg arg1) {
            UART_Params_init(&uartParams);
            uartParams.writeDataMode = UART_DATA_BINARY;
            uartParams.readDataMode = UART_DATA_BINARY;
            uartParams.readReturnMode = UART_RETURN_NEWLINE;
            uartParams.readEcho = UART_ECHO_OFF;
            uartParams.baudRate =19200;// baud rate of the interface
            uart = UART_open(Board_UART0, &uartParams);
            if (uart == NULL)
            {
                System_abort("Error opening the UART");
            }

            //Entering the configuration mode
                        tx_buffer_config[0]=CMD_CONFIG;
                        UART_write(uart, &tx_buffer_config, 1);
                        UART_read(uart, &rx_buffer_config, 1);
                        System_printf("sending the request for config mode\n");
                        System_printf("received ACK %d\n",rx_buffer_config[0]);
                        System_flush();

                        //Reading the ID using the Read ID command
                                    tx_buffer_config[0]=CMD_ID;
                                    UART_write(uart, &tx_buffer_config, 1);
                                    UART_read(uart, &rx_buffer_id, 12);
                                    System_printf("sending the request to send ID\n");
                                    System_flush();
                                    for(i=0;i<12;i++){
                                        if (i<4){
                                            System_printf("ID[%d] is %02x\n",i,rx_buffer_id[i]);
                                            System_flush();
                                        }
                                        else {
                                            System_printf("PAC[%d] is %02x\n",i,rx_buffer_id[i]);
                                        }
                                    }
                                    System_flush();

                                    //Sending the Exit Command to leave the configuration mode
                                                tx_buffer_config[0]=CMD_IDLE;
                                                UART_write(uart, &tx_buffer_config, 1);
                                                System_printf("sending the IDLE mode Req\n\n");
                                                System_flush();

                                               while(1)
                                               {
                                                   Water_Level();
                                                   Turbidity();
                                                   pH();

                                                   /* tx_buffer_data[0] --> command
                                                      tx_buffer_data[1] --> Safety
                                                      tx_buffer_data[2] --> turbidity
                                                      tx_buffer_data[3] --> pH
                                                      tx_buffer_data[4] --> water level*/


                                                   // For safe
                                                   if(tx_buffer_data[2] > 4 && tx_buffer_data[3] > 20 && tx_buffer_data[3] < 30){
                                                         System_printf("S\n\n");
                                                         tx_buffer_data[1]=0x01;
                                                   }
                                                   else{
                                                       System_printf("U\n\n");   //For unsafe
                                                       tx_buffer_data[1]=0x02;
                                                   }

                                                   //tx_buffer_data[1]=0x02;


                                                   System_printf("tx_buffer_data[0]: %d\n", tx_buffer_data[0]);
                                                   System_printf("tx_buffer_data[1]: %d\n", tx_buffer_data[1]);
                                                   System_printf("tx_buffer_data[2]: %d\n", tx_buffer_data[2]);
                                                   System_printf("tx_buffer_data[3]: %d\n", tx_buffer_data[3]);
                                                   System_printf("tx_buffer_data[4]: %d\n\n", tx_buffer_data[4]);

                                                   UART_write(uart, &tx_buffer_data, 5);
                                                   System_printf("sending Data \n\n");
                                                   System_flush();
                                                   Task_sleep(12000000);
                                               }
}

/*
 *  ======== taskFxn0 ========
 *  Open an ADC instance and get a sampling result from a one-shot conversion.
 */

//Void taskFxn_Water_Level(UArg arg0, UArg arg1)
Void Water_Level()
{
    //uint16_t     i;
    ADC_Handle   adc;
    ADC_Params   params;
    int_fast16_t res;


    ADC_Params_init(&params);
    adc = ADC_open(Board_ADC0, &params);

    if (adc == NULL) {
        System_abort("Error initializing WATER LEVEL SENSOR\n");
    }
    else {
        System_printf("WATER LEVEL SENSOR initialized\n");
    }

    /* Blocking mode conversion */

        //while(1){

            adcValue_level = 0;
            res = ADC_convert(adc, &adcValue_level);

            System_printf("Water Level: %d\n", adcValue_level);

            if (res == ADC_STATUS_SUCCESS) {
                if (adcValue_level < 0x3E8){
                    //Task_sleep((UInt)arg0);
                    System_printf("Water Level is safe\n\n");
                    tx_buffer_data[4]=0x01;
                    PIN_setOutputValue(ledPinHandle, Board_LED1, 1);
                }

                else {
                    //Task_sleep((UInt)arg0);
                    System_printf("Water Level is approaching limit\n\n");
                    tx_buffer_data[4]=0x02;
                    PIN_setOutputValue(ledPinHandle, Board_LED0, 1);
                }

            }

            else {
                System_printf("Failed to read water level\n");
            }

            ADC_close(adc);

            PIN_setOutputValue(ledPinHandle, Board_LED1, 0);
            PIN_setOutputValue(ledPinHandle, Board_LED0, 0);

            System_flush();

            tx_buffer_data[0]=0x04;
            //Data to be sent

            //UART_write(uart, &tx_buffer_data, 2);
            //System_printf("sending Data \n");
            //System_flush();
        //}
            //Task_sleep(30000);
}

//Void taskFxn_Turbidity(UArg arg0, UArg arg1)
Void Turbidity()
{
    //uint16_t     i;
    ADC_Handle   adc;
    ADC_Params   params;
    int_fast16_t res;
    uint32_t Res, volt;


    ADC_Params_init(&params);
    adc = ADC_open(Board_ADC1, &params);

    if (adc == NULL) {
        System_abort("Error initializing TURBIDITY SENSOR\n");
    }
    else {
        System_printf("TURBIDITY SENSOR initialized\n");
    }

    /* Blocking mode conversion */
        //int i=0;


      // while(1){
            //i++;
            adcValue_turbidity = 0;

            res = ADC_convert(adc, &adcValue_turbidity);
            //adcValue_turbidity = (adcValue_turbidity * 5)/1024;

            Res = ADC_convertRawToMicroVolts(adc, adcValue_turbidity);
            volt = (Res/1000000.0) + 2;

            System_printf("adc: %d and Voltage: %d\n\n", adcValue_turbidity, volt);

            if (res == ADC_STATUS_SUCCESS) {
                if (adcValue_turbidity < 0x3E8){

                    PIN_setOutputValue(ledPinHandle, Board_LED1, 1);
                }

                else {

                    PIN_setOutputValue(ledPinHandle, Board_LED0, 1);
                }

            }

            else {
                System_printf("Failed to read turbidity\n");
            }

            ADC_close(adc);

            PIN_setOutputValue(ledPinHandle, Board_LED1, 0);
            PIN_setOutputValue(ledPinHandle, Board_LED0, 0);

            System_flush();

            adcValue_turbidity=adcValue_turbidity/1000;
            tx_buffer_data[2]=adcValue_turbidity;

}

//Void taskFxn_pH(UArg arg0, UArg arg1)
Void pH()
{
        ADC_Handle   adc;
        ADC_Params   params;
        int_fast16_t res;
        uint32_t Res, volt;

        ADC_Params_init(&params);
           adc = ADC_open(Board_ADC2, &params);

           if (adc == NULL) {
               System_abort("Error initializing pH SENSOR\n");
           }
           else {
               System_printf("pH SENSOR initialized\n");
           }

               adcValue_pH = 0;

               res = ADC_convert(adc, &adcValue_pH);
               Res = ADC_convertRawToMicroVolts(adc, adcValue_pH);
               volt = Res/1000000.0;

               if (res == ADC_STATUS_SUCCESS) {
                   System_printf("adc: %d, Res: %d, Voltage: %d\n\n", adcValue_pH, Res, volt);
               }
               else {
                   System_printf("Failed to read pH\n\n");
               }

               ADC_close(adc);
               System_flush();

               adcValue_pH=adcValue_pH/100;
               tx_buffer_data[3]=adcValue_pH;

}

/*
 *  ======== main ========
 */
int main(void)
{
    Task_Params taskParams;

    /* Call board init functions */
    Board_initGeneral();
    Board_initADC();
    // Board_initI2C();
    // Board_initSPI();
    Board_initUART();
    // Board_initWatchdog();

    /* Create tasks */

        /* sigfox */
        Task_Params_init(&taskParams);
        taskParams.stackSize = TASKSTACKSIZE_sigfox;
        taskParams.stack = &task3Stack;
        Task_construct(&task3Struct, (Task_FuncPtr)taskFxn_sigfox, &taskParams, NULL);



        /* Open LED pins */
    ledPinHandle = PIN_open(&ledPinState, ledPinTable);
    if(!ledPinHandle) {
        System_abort("Error initializing board LED pins\n");
    }

    System_printf("Starting the example\nSystem provider is set to SysMin. "
                  "Halt the target to view any SysMin contents in ROV.\n\n");
    /* SysMin will only print to the console when you call flush or exit */
    System_flush();

    /* Start BIOS */
    BIOS_start();

    return (0);


}
